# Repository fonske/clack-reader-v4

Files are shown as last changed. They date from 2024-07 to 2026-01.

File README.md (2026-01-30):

# Clack Reader v4
 Esphome component for Clack WS PI (disc valve) Ecosoft LESS and WS1 softener with M5stack TOF sensor saltlevel detection
 
 Relay for control of the chlorinator module from AQMOS
 and Power measurement with ina3221

 Automatic recognision of the softener steps and measure the liters and m3 softened water by reading the clack flowmeter

## 4 Versions / Branches
main: Clack WS PI valve (DiscValve) (ECOSOFT LESS-10 / 15 / 20 from AQMOS)

ws1: Clack WS1 valve (CM(x) from AQMOS)

ws1_usa: Clack WS1 valve with Gallons and Inches / US version

ws1_no_tof: Clack WS1 valve without the TOF sensor code (in case of TOF failure/damaged by water)

Remark: Make sure to copy water_flow.h and tof_vl53l1x.h to your esphome directory before compiling the clack.yaml
There have been some bigger updates to the latest code: added L/min and alarm, also lovelace home assistant menu has been updated.

Remark2: 6 august 2024: Added history regeneration and test button motor pulse to step through regeneration (with time delays stil working between steps)
[example EN](/readme/last_changes_august_2024.jpg)
[example NL](/readme/laaste_wijzigingen_august_2024.jpg)

Remark3: 17 august 2024: Added more options to show the regeneration cycle. Pre fill (dry salt tank) and Post fill (wet salt tank)
Both with or without the 2nd backwash programmed  (between brine and rinse)

      # Pre fill no 2nd Backwash  : FILL/SERVICE/BACKWASH/BRINE/RINSE
      # Pre fill 2nd Backwash     : FILL/SERVICE/BACKWASH/BRINE/BACKWASH2/RINSE
      # Post fill no 2nd Backwash : BACKWASH/BRINE/RINSE/FILL
      # sPost fill 2nd Backwash   : BACKWASH/BRINE/BACKWASH2/RINSE/FILL   

When delivered the Clack reader has already the correct code on the Atom S3 esp.
If needed, there can be downloaded new firmware to the Atom.

***
It is important to connect the TOF sensor to the 4p grove connector near the Atom S3. This needs to be done, before powering the PCB, otherwise the Atom will be in a reboot loop, and no wifi hotspot will be available to connect to.

 ## Dutch:
[README](/readme/clack_uitleg_nl.md)

## English:
[README](/readme/clack_explanation_en.md)

Help: Please open a issue on this git project.

Example

"Buy Me A Coffee" (https://www.buymeacoffee.com/ebbenberg)

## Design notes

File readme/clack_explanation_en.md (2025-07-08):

# Clack Reader V4 with Atom S3 lite and TOF sensor

## Hardware
The kit includes:
- [Atom S3 lite](https://www.tinytronics.nl/shop/nl/development-boards/microcontroller-boards/met-wi-fi/m5stack-atom-s3-lite-esp32-s3-development-board) from M5stack
- [TOF1 sensor](https://www.tinytronics.nl/shop/nl/platformen-en-systemen/m5stack/unit/m5stack-tof-unit)  (vl53l0x) or [TOF2 sensor](https://shop.m5stack.com/products/time-of-flight-distance-unit-vl53l1x) (vl53l1x) from M5stack
  - TOF1 can measure with a Grove cable up to 5 meters (2x 2m + 1x 1m with connector blocks)
  - TOF2 can measure with a Grove cable up to 3 meters (1x 2m + 1x 1m with connector blocks)
- PCB with connectors ([visual overview](../readme/Clack_reader_v4_connections_on_clack_ws1_EN.pdf) of connections)
  - Power in/out - Passthrough connections to monitor power usage and regeneration steps (4-wire connector)
  - Flowmeter in/out - Passthrough connections to monitor water usage (3-wire connector, on back of PCB)
  - DP-SW - Allows for a delayed or immediate regen, or can prevent a regen. Functionality depends on the settings in the softener control itself (refer to the manual)
- [3D printed](../readme/clack_tof-holder.stl)  TOF sensor housing which can be attached to the salt reservoir lid with two stainless steel M4 bolts and nuts

> [!WARNING]
> It is important to connect the TOF sensor to the 4p Grove connector <ins>near</ins>, not on, the Atom S3. This needs to be done before powering the PCB, otherwise the Atom will enter a reboot loop and the Wi-Fi hotspot will not be available to connect to.

## Hardware Images
| Image | Description |
| --- | --- |
| [pcb_front.jpg](../readme/pcb_front.jpg) | Front of Clack Reader |
| [pcb_back.jpg](../readme/pcb_back.jpg) | Back of Clack Reader |
| [mount_position_image1.jpg](../readme/mount_position_image1.jpg) | Best location for mounting Clack Reader inside the Clack WS1 housing |
| [mount_position_image2.jpg](../readme/mount_position_image2.jpg) | Best location for mounting Clack Reader inside the Clack WS1 housing |

## Firmware
The Clack Reader PCB is programmed in ESPHome and arrives preflashed. You can choose to use the supplied version or reflash from this Git repo.

If using the preflashed version, power on the Clack Reader (with the TOF sensor attached), connect to the `Clack` hotspot using the password `configesp`, and enter your network's Wi-Fi details.

# Home Assistant

## Lovelace Dashboard
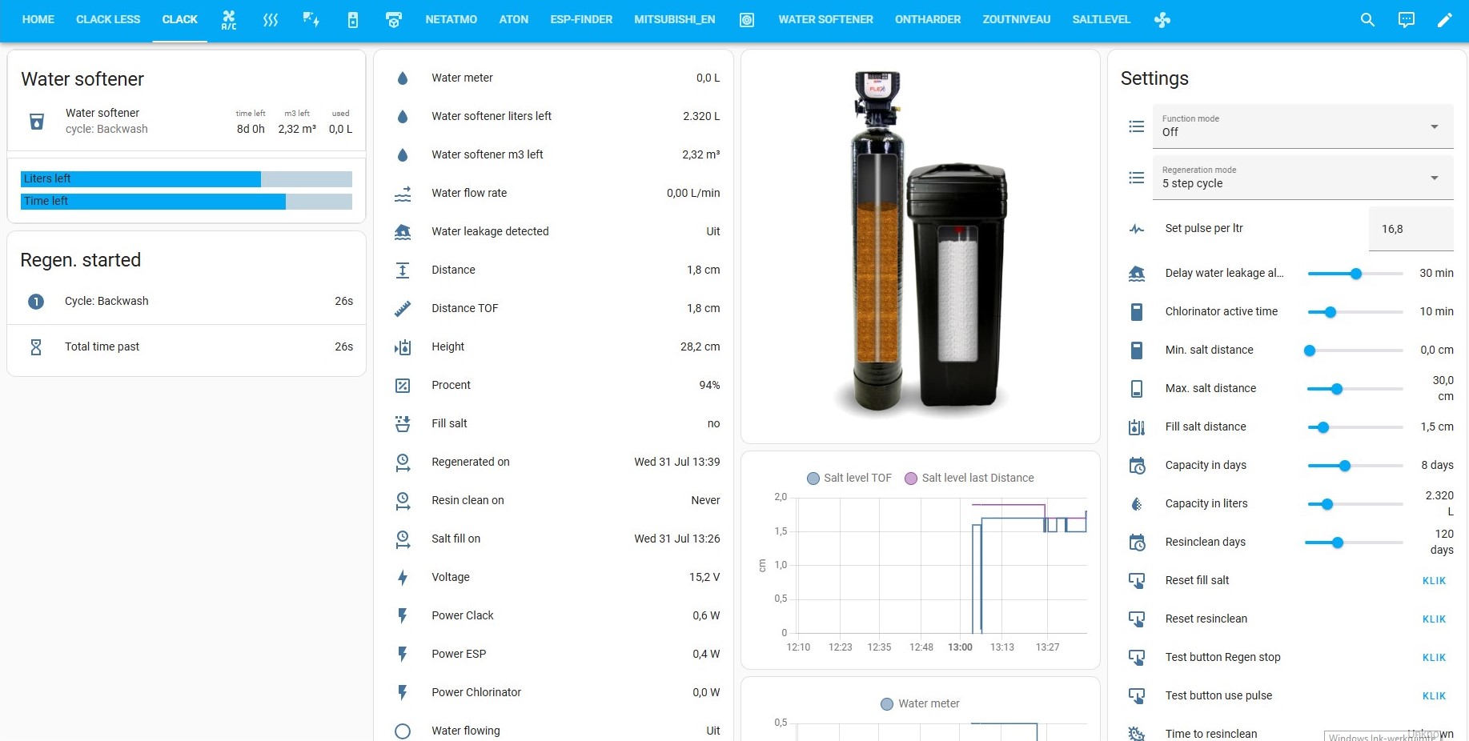
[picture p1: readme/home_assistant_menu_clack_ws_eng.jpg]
Example


To add the dashboard shown above to Home Assistant:
1. Create a `/www/images` folder in your `homeassistant` directory
1. Copy the images from [/www/images](../www/images) into the new folder. These images support the salt level simulation view.
1. Navigate to your Home Assistant dashboard
1. At the top-right, click the pencil (edit dashboard)
1. Click the three dots and select 'Raw configuration editor'
1. Add the text from the appropriate dashboard YAML file from the [homeassistant](../homeassistant) folder of this repo (e.g., [lovelace_menu_Post_fill_with_2nd_backwash_dn_brine_EN.yaml](../homeassistant/lovelace_menu_Post_fill_with_2nd_backwash_dn_brine_EN.yaml)) and save
1. You will now have a new Clack view in Home Assistant

> [!IMPORTANT]
> To properly view the status bar, use [HACS](https://hacs.xyz) to install the following frontend applications (subject to change):
> - bar-card https://github.com/spacerokk/bar-card
> - multiple-entity-row
> - stack-in-card

## Automations
It is possible to receive notifications on a mobile phone running the Home Assistant app. For example, when a possible water leak is detected or when salt runs low. Sample automations are provided in [clack_en.yaml](../homeassistant/clack_en.yaml). The options below can be used to add these automations to Home Assistant.

> [!IMPORTANT]
> Modify the `action` values to use your own mobile device (e.g., replace `- action: notify.mobile_app_iphone_van_a_c_a`)

### Option 1 - Use Home Assistant [Packages](https://www.home-assistant.io/docs/configuration/packages/) functionality
1. Create a folder under `/config`, preferably named `packages`, and copy [clack_en.yaml](../homeassistant/clack_en.yaml) to the directory
1. Adjust your `configuration.yaml` to add:

>```yml
> homeassistant:
>   packages: !include_dir_named packages
> ```

3. Restart Home Assistant

> [!WARNING]
> While automations added using the [Packages](https://www.home-assistant.io/docs/configuration/packages/) pattern are visible in Home Assistant on the `Settings/Automations` screen, they are not modifiable via the Home Assistant UI. To modify them, edit the package YAML file and restart Home Assistant.

### Option 2 - Merge clack_en.yaml with automations.yaml
Merge the `automations:` section of [clack_en.yaml](../homeassistant/clack_en.yaml) with automations.yaml (pay attention to indentations).

## Configuration

Use the sliders on the dashboard to configure the system.

> [!TIP]
> A diagram explaining min/max salt distance can be found [here.](../readme/min_max_EN.jpg)

| Setting | Description | Example |
| --- | --- | ---- |
| Delay water leakage alarm | Minutes of constant water flow that will trigger `binary_sensor.clack_leakage_detected` to turn `true`, allowing automations (alerts) to trigger | 30 min |
| Min. salt distance | Distance between the TOF sensor and the salt <ins>when the salt container is full</ins> | 10 cm. |
| Max. salt distance | Distance between the TOF sensor and the salt <ins>when the salt is at its lowest level</ins> (empty)| 35 cm. |
| Fill salt distance | Centimeters of salt remaining in the tank, below which `sensor.clack_fill_salt` turns `true` and automations (alerts) may trigger | 5 cm. |
| Capacity in days | Number of days the Clack controller is set to regen at if the liters of capacity has not yet been exceeded | 14 days |
| Capacity in liters | Liters of capacity that the Clack controller displays immediately after a regen | 3500 ltr. |
| Pulses per ltr | Pulse meter is used to measure water flow. It measures pulses per minute. To convert pulses into liters of water this setting is used. The bigger this value the slower water flow will be. | 16.3 pulses/ltr. |
| Water flow timeout | If no water flow pulse is detected in this amount of time then water flow will be considered 0. The bigger is this value the longer it will take for water flow meter to detect that flow has stopped. But the bigger this value the smaller quantities of flowing water will be detectable by the water flow meter. | 7 s |

## Explanation of Operation

### Salt Measurement Logic
Since many water softeners have water above the salt (small salt reservoir), there is a smart function built into the distance measurement.

The sensor measures the distance downwards to the salt. That measured distance should be expected to only increase as the salt depletes.
Because of this, shorter distances are not recorded as the most recent value, only longer ones. This way, water rising above the salt does not affect the measurement.

There are two readings: Distance and TOF Distance.
Distance is the measurement with the smart function. TOF Distance is continuously measured every 10 seconds but has no effect on the 'Clack salt level percent' and does not affect Distance unless the it measures greater than Distance.

### Refilling Salt

When refilling your salt container, press the 'Reset fill salt' button on the dashboard. This will equalize the TOF Distance and Distance values, thereby resetting the distance measurement so that the new salt level can be measured and recorded again. Recall that the smart function would otherwise not let Distance increase.

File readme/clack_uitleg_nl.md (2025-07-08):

# Clack Reader V4 met Atom S3 lite en TOF sensor

## Hardware
De kit bevat:
- [Atom S3 lite](https://www.tinytronics.nl/shop/nl/development-boards/microcontroller-boards/met-wi-fi/m5stack-atom-s3-lite-esp32-s3-development-board) van M5stack
- [TOF1 sensor](https://www.tinytronics.nl/shop/nl/platformen-en-systemen/m5stack/unit/m5stack-tof-unit) (vl53l0x) of [TOF2 sensor](https://shop.m5stack.com/products/time-of-flight-distance-unit-vl53l1x) (vl53l1x) van M5stack
  - TOF1 kan met een Grove kabel tot 5 meter meten (2x 2m + 1x 1m met connectorblokje)
  - TOF2 kan met een Grove kabel tot 3 meter meten (1x 2m + 1x 1m met connectorblokje)
- PCB met connectors ([visueel overzicht](../readme/Clack_reader_v4_connections_on_clack_ws1_EN.pdf) van de aansluitingen)
  - Stroom in/uit - Doorgeefverbindingen om het stroomverbruik en regeneratiestappen te monitoren (4-draads connector)
  - Flowmeter in/uit - Doorgeefverbindingen om het waterverbruik te monitoren (3-draads connector, aan de achterkant van de PCB)
  - DP-SW - Hiermee kan een vertraagde of onmiddellijke regeneratie worden gestart of kan regeneratie worden voorkomen. De functionaliteit hangt af van de instellingen in de waterontharder zelf (raadpleeg de handleiding)
- [3D-geprinte](../readme/clack_tof-holder.stl) TOF sensorbehuizing die met twee roestvrijstalen M4 bouten en moeren aan het deksel van het zoutreservoir kan worden bevestigd

> [!WARNING]
> Het is belangrijk om de TOF sensor aan te sluiten op de 4p Grove connector <ins>dichtbij</ins>, niet op, de Atom S3. Dit moet gebeuren voordat de PCB van stroom wordt voorzien, anders zal de Atom in een herstartlus komen en zal de Wi-Fi hotspot niet beschikbaar zijn om verbinding mee te maken.

## Hardware afbeeldingen
| Afbeelding | Beschrijving |
| --- | --- |
| [pcb_front.jpg](../readme/pcb_front.jpg) | Voorkant van Clack Reader |
| [pcb_back.jpg](../readme/pcb_back.jpg) | Achterkant van Clack Reader |
| [mount_position_image1.jpg](../readme/mount_position_image1.jpg) | Beste locatie voor het monteren van Clack Reader in de Clack WS1 behuizing |
| [mount_position_image2.jpg](../readme/mount_position_image2.jpg) | Beste locatie voor het monteren van Clack Reader in de Clack WS1 behuizing |

## Firmware
De Clack Reader PCB is geprogrammeerd in ESPHome en wordt vooraf geflasht geleverd. Je kunt ervoor kiezen om de meegeleverde versie te gebruiken of opnieuw te flashen vanuit deze Git-repo.

Als je de vooraf geflashte versie gebruikt, schakel dan de Clack Reader in (met de TOF sensor aangesloten), maak verbinding met de `Clack` hotspot met het wachtwoord `configesp`, en voer de Wi-Fi gegevens van je netwerk in.

# Home Assistant

## Lovelace Dashboard
Voorbeeld

Om het bovenstaande dashboard toe te voegen aan Home Assistant:
1. Maak een map `/www/images` in je `homeassistant` directory
1. Kopieer de afbeeldingen van [/www/images](../www/images) naar de nieuwe map. Deze afbeeldingen ondersteunen de weergave van de zoutniveau-simulatie.
1. Navigeer naar je Home Assistant dashboard
1. Klik rechtsboven op het potlood (dashboard bewerken)
1. Klik op de drie puntjes en selecteer 'Ruwe configuratie editor'
1. Voeg de tekst toe van het juiste dashboard YAML bestand uit de [homeassistant](../homeassistant) map van deze repo (bijv. [lovelace_menu_Post_fill_with_2nd_backwash_dn_brine_NL.yaml](../homeassistant/lovelace_menu_Post_fill_with_2nd_backwash_dn_brine_NL.yaml)) en sla op
1. Je hebt nu een nieuwe Clack weergave in Home Assistant

> [!IMPORTANT]
> Om de statusbalk correct weer te geven, gebruik [HACS](https://hacs.xyz) om de volgende frontend applicaties te installeren (onder voorbehoud van wijzigingen):
> - bar-card  https://github.com/spacerokk/bar-card
> - multiple-entity-row
> - stack-in-card

## Automatiseringen
Het is mogelijk om meldingen te ontvangen op een mobiele telefoon die de Home Assistant app gebruikt. Bijvoorbeeld wanneer een mogelijk waterlek wordt gedetecteerd of wanneer het zout opraakt. Voorbeeldautomatiseringen zijn beschikbaar in [clack_nl.yaml](../homeassistant/clack_nl.yaml). De onderstaande opties kunnen worden gebruikt om deze automatiseringen toe te voegen aan Home Assistant.

> [!IMPORTANT]
> Pas de `action` waarden aan om je eigen mobiele apparaat te gebruiken (bijv. vervang `- action: notify.mobile_app_iphone_van_a_c_a`)

### Optie 1 - Gebruik de Home Assistant [Packages](https://www.home-assistant.io/docs/configuration/packages/) functionaliteit
1. Maak een map onder `/config`, bij voorkeur genaamd `packages`, en kopieer [clack_nl.yaml](../homeassistant/clack_nl.yaml) naar de directory
1. Pas je `configuration.yaml` aan om toe te voegen:

>```yml
> homeassistant:
>   packages: !include_dir_named packages
> ```

3. Herstart Home Assistant

> [!WARNING]
> Hoewel automatiseringen die zijn toegevoegd met behulp van het [Packages](https://www.home-assistant.io/docs/configuration/packages/) patroon zichtbaar zijn in Home Assistant op het `Settings/Automations` scherm, kunnen ze niet worden gewijzigd via de Home Assistant UI. Om ze te wijzigen, bewerk je het package YAML bestand en herstart je Home Assistant.

### Optie 2 - Voeg clack_en.yaml samen met automations.yaml
Voeg de `automations:` sectie van [clack_nl.yaml](../homeassistant/clack_nl.yaml) samen met automations.yaml (let op de inspringingen).

## Configuratie

Gebruik de schuifregelaars op het dashboard om het systeem te configureren.

> [!TIP]
> Een diagram dat de min/max zoutafstand uitlegt, is hier te vinden. [hier.](../readme/min_max_NL.jpg)

| Instelling | Beschrijving | Voorbeeld |
| --- | --- | ---- |
| Vertraging waterlek alarm | Minuten van constante waterstroom die `binary_sensor.clack_leakage_detected` zal activeren om `true` te worden, waardoor automatiseringen (meldingen) kunnen worden geactiveerd | 30 min |
| Min. zoutafstand | Afstand tussen de TOF sensor en het zout <ins>wanneer de zoutcontainer vol is</ins> | 10 cm |
| Max. zoutafstand | Afstand tussen de TOF sensor en het zout <ins>wanneer het zout op het laagste niveau is</ins> (leeg)| 35 cm |
| Vul zoutafstand | Inches zout die nog in de tank zit, waaronder `sensor.clack_fill_salt` `true` wordt en automatiseringen (meldingen) kunnen worden geactiveerd | 4 cm |
| Capaciteit in dagen | Aantal dagen dat de Clack controller is ingesteld om te regenereren als het aantal gallons capaciteit nog niet is overschreden | 14 dagen |
| Capaciteit in liters | Liters capaciteit die de Clack controller weergeeft direct na een regeneratie | 3500 ltr |

## Uitleg werking

### Zoutmeetlogica
Aangezien veel waterontharders water boven het zout hebben (klein zoutreservoir), is er een slimme functie ingebouwd in de afstandsmeting.

De sensor meet de afstand naar beneden tot het zout. Die gemeten afstand zou alleen moeten toenemen naarmate het zout afneemt.
Hierdoor worden kortere afstanden niet geregistreerd als de meest recente waarde, alleen langere. Op deze manier beïnvloedt het stijgende water boven het zout de meting niet.

Er zijn twee metingen: Afstand en TOF Afstand.
Afstand is de meting met de slimme functie. TOF Afstand wordt continu elke 10 seconden gemeten maar heeft geen invloed op het 'Clack zoutniveau percentage' en beïnvloedt de Afstand niet tenzij het groter meet dan de Afstand.

### Zout bijvullen

Bij het bijvullen van je zoutcontainer druk je op de 'Reset fill salt' knop op het dashboard. Dit zal de TOF Afstand en Afstand gelijkmaken, waardoor de afstandsmeting opnieuw wordt ingesteld zodat het nieuwe zoutniveau opnieuw kan worden gemeten en geregistreerd. Onthoud dat de slimme functie anders de Afstand niet zou laten toenemen.

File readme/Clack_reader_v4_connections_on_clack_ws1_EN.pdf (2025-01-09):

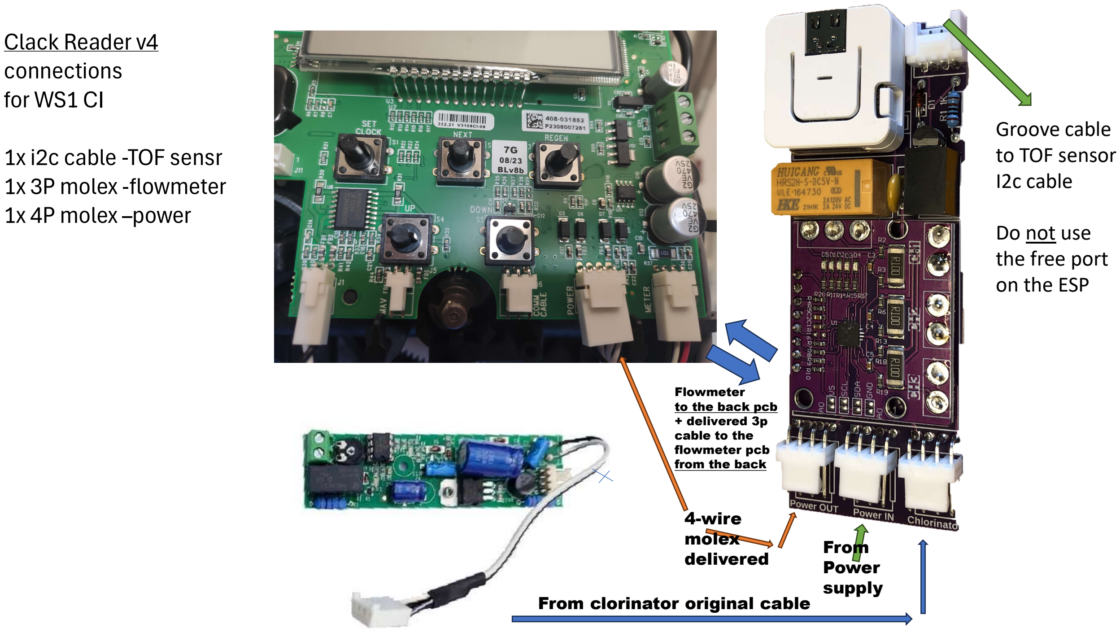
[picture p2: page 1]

4-wire
molex
delivered | From
| Power
| supply
From clorinator original cable

Flowmeter
to the back pcb
+ delivered 3p
cable to the
flowmeter pcb
from the back

Clack Reader v4
connections
for WS1 CI

1x i2c cable -TOF sensr
1x 3P molex -flowmeter
1x 4P molex –power

Groove cable
to TOF sensor
I2c cable

Do not use
the free port
on the ESP

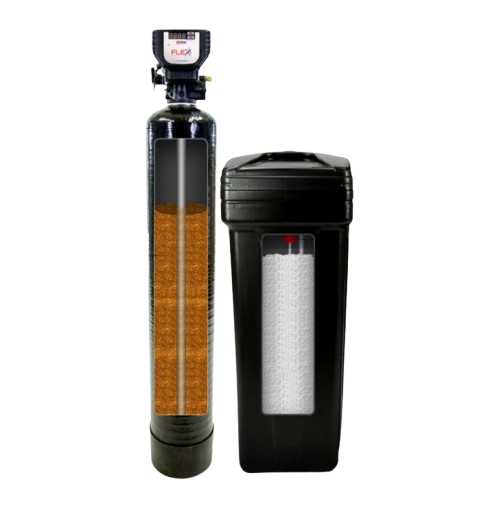
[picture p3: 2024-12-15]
www/images/softener100.png

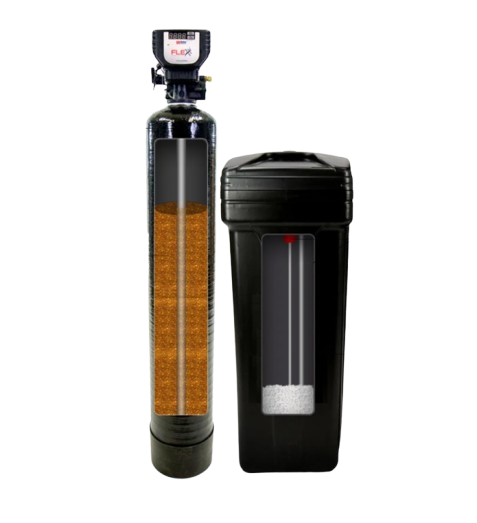
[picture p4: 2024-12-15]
www/images/softener10.png

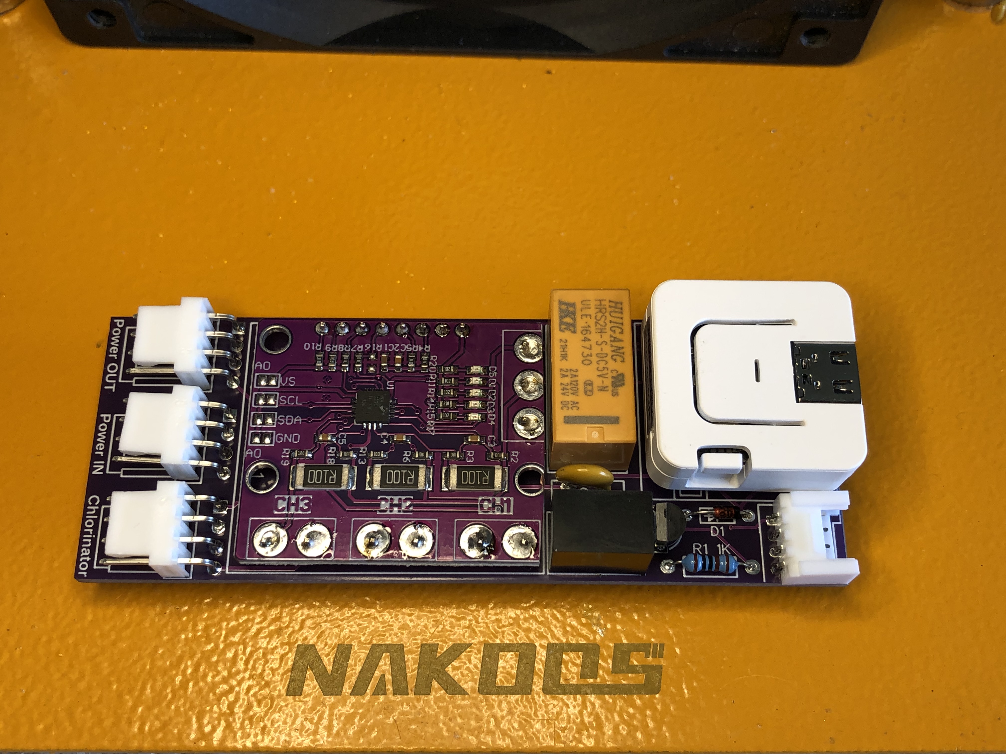
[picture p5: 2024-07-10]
readme/pcb_front.jpg

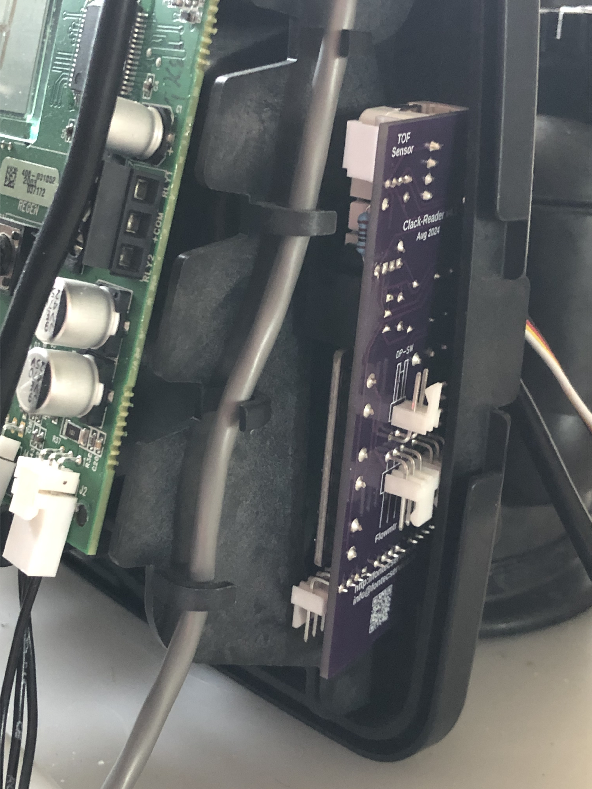
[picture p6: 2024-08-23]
readme/mount_position_image1.jpg

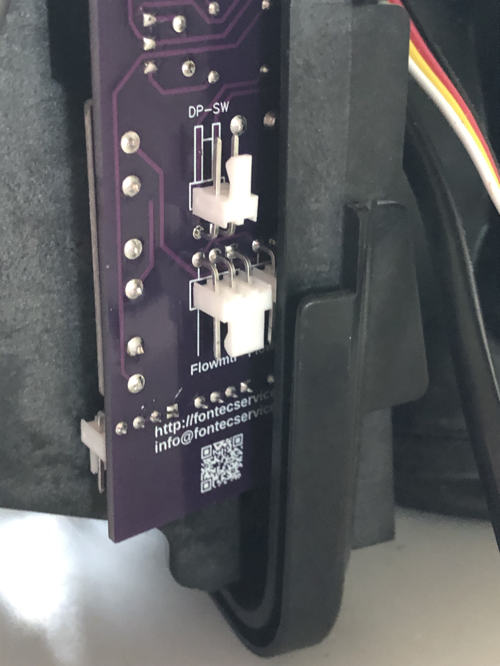
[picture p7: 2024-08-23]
readme/mount_position_image2.jpg

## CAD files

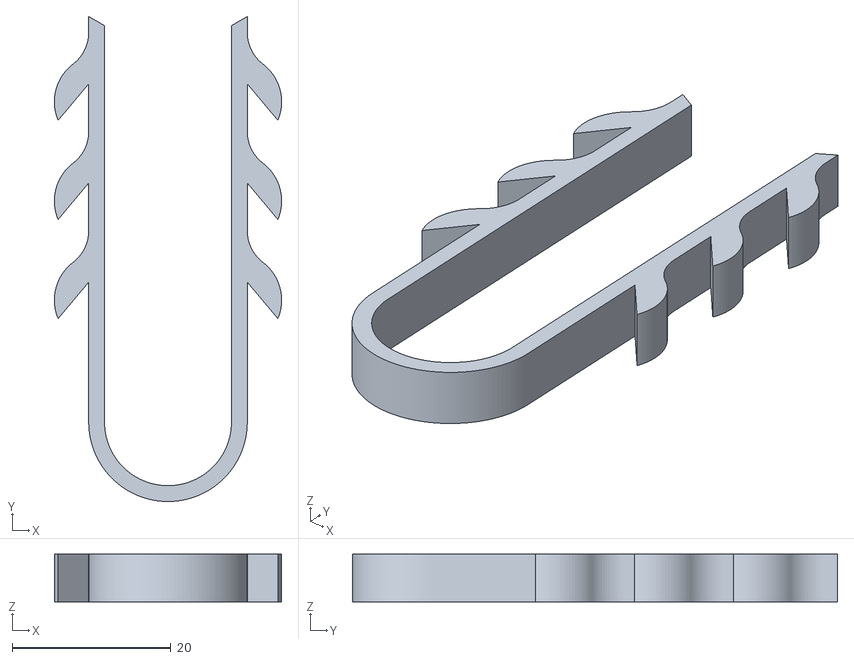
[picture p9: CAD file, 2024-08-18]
readme/Airgap_3d_thomox/Piepschuim_plug.stl
28.7 x 61.2 x 6.00

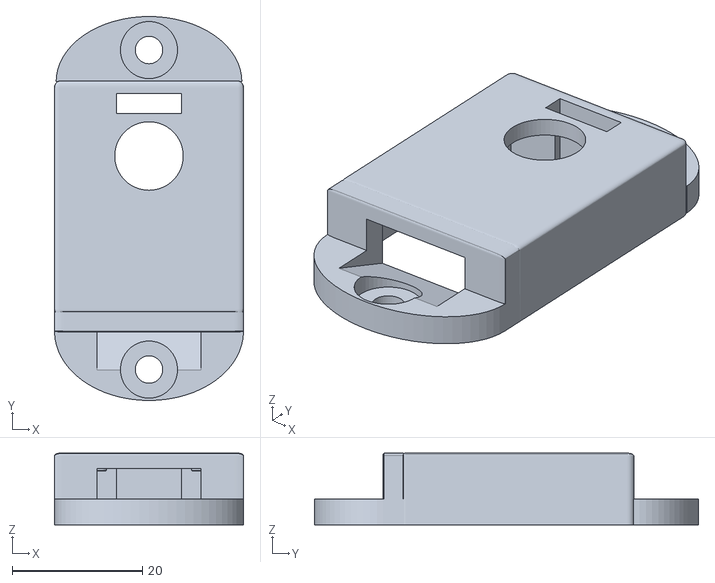
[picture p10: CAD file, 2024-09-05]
readme/clack_tof-holder.stl
29.0 x 58.9 x 11.0

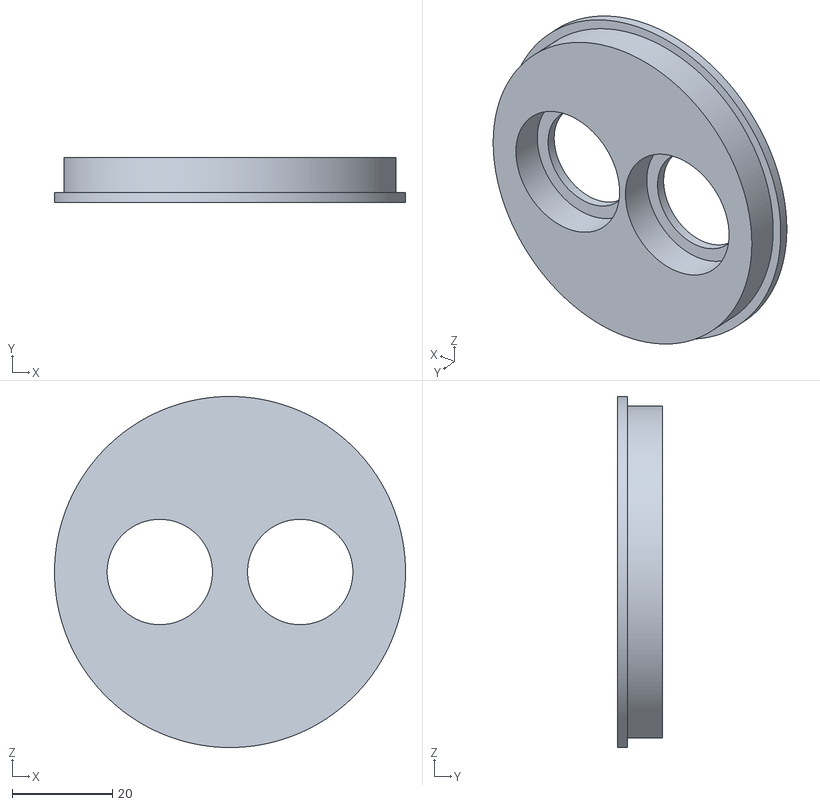
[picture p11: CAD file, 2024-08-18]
readme/Airgap_3d_thomox/Deksel airgap V2.stl
70.0 x 9.00 x 70.0

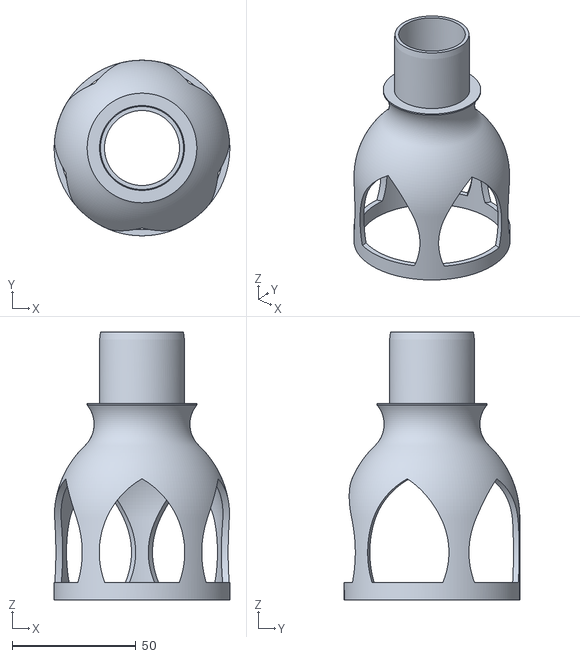
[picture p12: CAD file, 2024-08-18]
readme/Airgap_3d_thomox/Airgap_v4.stl
71.0 x 71.0 x 108.3

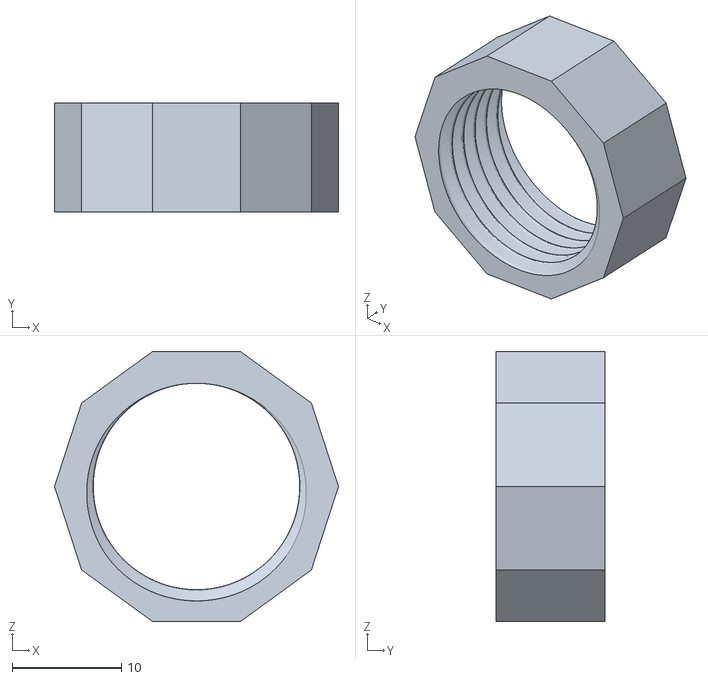
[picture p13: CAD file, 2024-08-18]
readme/Airgap_3d_thomox/half_inch_nut.stl
26.0 x 10.0 x 24.7

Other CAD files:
readme/Airgap_3d_thomox/Airgap_v4.f3d
readme/Airgap_3d_thomox/deksel airgap v2.f3d

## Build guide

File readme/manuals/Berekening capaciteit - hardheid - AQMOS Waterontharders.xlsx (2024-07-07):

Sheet: Dashboard
Selecteer je model: |  |  | Hardheid (°dH) | LESS-10 | -10%
LESS-10 |  |  |  | In liter (L) | In liter (L) | Model | C-waarde
 |  |  |  |  |  | LESS-10 | C 25
 |  |  | 7.5 | 3700 | 3300 | LESS-15 | C 37
 |  |  | 10 | 2800 | 2500 | LESS-20 | C 63
 |  |  | 11 | 2500 | 2200
Voer je waterhardheid in (°dH): |  |  | 12 | 2300 | 2100 | Voer bovenstaande waardes in bij C=. (Navigeer naar menu: ↳ + ⭣) Let op dat je de waterontharder hebt ingesteld op dH in plaats van PPM! (Zelfde menu, waarde "U" instellen op dH). Vergeet niet je hardheid in te stellen! (Navigeer naar menu: ↳ + ⭡)
10 |  |  | 13 | 2100 | 1900
 |  |  | 14 | 2000 | 1800
 |  |  | 15 | 1800 | 1600
De capaciteit van je waterontharder is: | 2800 |  | 16 | 1700 | 1500
Wij raden de volgende waarde aan om in te stellen (10% marge): | 2500 | ⭠Voer deze waarde NIET in bij C=. Deze waarde is puur indicatief. Zie de C waarde naast de tabel. | 17 | 1600 | 1400
Er zitten meerdere "storende ionen" in het water die vastgehouden worden door het hars. Denk bijvoorbeeld aan ijzer, mangaan, natrium. Daarom raden wij een kleine marge aan. (Dit is ook de reden waarom harsreiniger gebruiken belangrijk is.) |  |  | 18 | 1500 | 1400
 |  |  | 19 | 1400 | 1300
 |  |  | 20 | 1400 | 1200
 |  |  | 21 | 1300 | 1200
 |  |  | 22 | 1200 | 1100
 |  |  | 23 | 1200 | 1000
 |  |  | 24 | 1100 | 1000
 |  |  | 25 | 1100 | 1000
 |  |  | 26 | 1000 | 900
 |  |  | 27 | 1000 | 900
 |  |  | 28 | 1000 | 900
 |  |  | 29 | 900 | 800
 |  |  | 30 | 900 | 800
 |  |  | 31 | 900 | 800
 |  |  | 32 | 800 | 700
 |  |  | 33 | 800 | 700
 |  |  | 34 | 800 | 700
 |  |  | 35 | 800 | 700

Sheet: Data
Model? | Column1 | X Hars | Operating capacity
Anders |  | 10 | 0.499
LESS-10
LESS-15
LESS-20
R2D2-32
R2D2-48
R2D2-72

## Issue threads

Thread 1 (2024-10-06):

Pulse conter needed for flow meter?

OwlBawl, 2024-10-06:
Errors in log related to water flow meter in HA

```
2024-10-06 11:48:42.576 WARNING (MainThread) [homeassistant.components.sensor] Entity sensor.clack_water_flow_rate (<class 'homeassistant.components.esphome.sensor.EsphomeSensor'>) is using state class 'measurement' which is impossible considering device class ('water') it is using; expected None or one of 'total', 'total_increasing'; Please update your configuration if your entity is manually configured, otherwise create a bug report at https://github.com/home-assistant/core/issues?q=is%3Aopen+is%3Aissue+label%3A%22integration%3A+esphome%22
2024-10-06 11:48:42.577 WARNING (MainThread) [homeassistant.components.sensor] Entity sensor.clack_water_flow_rate (<class 'homeassistant.components.esphome.sensor.EsphomeSensor'>) is using native unit of measurement 'L/min' which is not a valid unit for the device class ('water') it is using; expected one of ['gal', 'm³', 'CCF', 'ft³', 'L']; Please update your configuration if your entity is manually configured, otherwise create a bug report at https://github.com/home-assistant/core/issues?q=is%3Aopen+is%3Aissue+label%3A%22integration%3A+esphome%22
```

OwlBawl, 2024-10-06:
Found this one, changed in my code, would test:
device_class: volume_flow_rate
state_class: measurement

fonske, 2024-10-06:
Thank you.

I have made the changes.

Closed 2024-10-06.

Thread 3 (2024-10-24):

Need your help... after ESPhome 2024.10.2 Update it gone "offline" and can't get it work.

OwlBawl, 2024-10-24:
Can see it as WiFi client in router but ESPhome dont establish connection, web portal not working also.
First symptom after update was False "Regen start / Regen end" with "binary_sensor.clack_block_regen" active
Reseted it with "button.clack_test_button_regen_stop" to restore work, then rebooted the esp32 and thats all. Tried upload recompiled firmware via OTA but also no luck...

thedudefxp, 2024-10-24:
Does he get ip ?
i had some thing last time its was lost the information in secrets.yalm. It show on router wifi but no ip lease

fonske, 2024-10-24:
I have just updated with the newest version of esphome but everything works.

Do you use the correct github branch for your model?
And check  secrets.yaml indeed if correct setting for your wifi

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

OwlBawl, 2024-10-24:
As i see arduiono framework also updated recently... maybe that's the problem also... don't know

OwlBawl, 2024-10-24:
> Does he get ip ? i had some thing last time its was lost the information in secrets.yalm. It show on router wifi but no ip lease

yes, it receives IP from router and router even ping it
tries ping from HA terminal successfully also.

OwlBawl, 2024-10-24:
recompiled using exteranal git component - also not API connection.... while pinging

fonske, 2024-10-24:
Is your TOF sensor connected?  Otherwise you could have reboots
best to have it on Clack power and not usb, for clack reader V4
warning: do not connect or disconnect any power cables when power is on.

OwlBawl, 2024-10-24:
Would check, but didn't touch it
It connectecd with cable to Clack reader, and clack reader powered by Clack 15V? (as i remember voltage)

fonske, 2024-10-24:
Yes i think its correct
https://github.com/fonske/clack-reader-v4/blob/ws1/readme/Clack_reader_v4.1_connections_on_clack_ws1.pdf

OwlBawl, 2024-10-24:
TOF cords are connected...
It sent false Regen start at night (the regen is scheduled on 14:00 at day, and resourse wasn't used yet for regen)
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
co

In HA from same 3:20 sensors resetet to 0 as it was regen, and from 5:10 all entities became unavailable...
I succesfully rebooted it once in the morning 8:15 and it established API connection, and after 9:10 it gone offline till now...

Made few OTA updates already, rebotted my Unifi router and AP's... reboted HA and so on.

OwlBawl, 2024-10-24:
> Yes i think its correct https://github.com/fonske/clack-reader-v4/blob/ws1/readme/Clack_reader_v4.1_connections_on_clack_ws1.pdf

yes, it's connected from the beginning as it sholt ad worked almost 2 mnths so
(from ~9.09.24)
But yes, anything could happen ofcourse

OwlBawl, 2024-10-24:
But as i see in router history - it don't powercycle. it connects to wifi and that's all
I can use captivate_portal for OTA blocking it from WiFi connection but web_portal not responsive

fonske, 2024-10-24:
Maybe you can try a basic configuration first
https://github.com/fonske/clack-reader-v4/blob/ws1/esphome/clack_test.yaml

To see if a tof sensor connection is a problem or not  (reboots when there is a problem with it)

OwlBawl, 2024-10-24:
That's seems good.
I can open web portal, can see it in ESPhome now

Should I wait for reboots some time?

OwlBawl, 2024-10-24:
`INFO ESPHome 2024.10.2
INFO Reading configuration /config/esphome/clack-reader-v4.yaml...
WARNING GPIO35 is used by the PSRAM interface on ESP32-S3R8 / ESP32-S3R8V and should be avoided on these models
INFO Starting log output from 10.10.20.213 using esphome API
INFO Successfully connected to clack-test @ 10.10.20.213 in 0.066s
INFO Successful handshake with clack-test @ 10.10.20.213 in 0.019s
[21:22:29][I][app:100]: ESPHome version 2024.10.2 compiled on Oct 24 2024, 21:17:59
[21:22:29][C][wifi:600]: WiFi:
[21:22:29][C][wifi:428]:   Local MAC: 34:B7:DA:57:3B:40
[21:22:29][C][wifi:433]:   SSID: 'daad.iot'[redacted]
[21:22:29][C][wifi:436]:   IP Address: 10.10.20.213
[21:22:29][C][wifi:440]:   BSSID: 7A:45:58:17:ED:C1[redacted]
[21:22:29][C][wifi:441]:   Hostname: 'clack-test'
[21:22:29][C][wifi:443]:   Signal strength: -60 dB ▂▄▆█
[21:22:29][C][wifi:447]:   Channel: 6
[21:22:29][C][wifi:448]:   Subnet: 255.255.255.0
[21:22:29][C][wifi:449]:   Gateway: 10.10.20.1
[21:22:29][C][wifi:450]:   DNS1: 10.10.20.1
[21:22:29][C][wifi:451]:   DNS2: 0.0.0.0
[21:22:29][C][logger:185]: Logger:
[21:22:29][C][logger:186]:   Level: DEBUG
[21:22:29][C][logger:188]:   Log Baud Rate: 0
[21:22:29][C][logger:189]:   Hardware UART: USB_CDC
[21:22:29][C][logger:193]:   Level for 'esp32.preferences': DEBUG
[21:22:29][C][logger:193]:   Level for 'sensor': DEBUG
[21:22:29][C][logger:193]:   Level for 'text_sensor': DEBUG
[21:22:29][C][logger:193]:   Level for 'switch': DEBUG
[21:22:29][C][logger:193]:   Level for 'button': DEBUG
[21:22:29][C][logger:193]:   Level for 'number': DEBUG
[21:22:29][C][logger:193]:   Level for 'component': ERROR
[21:22:29][C][uptime.sensor:033]: Uptime Sensor 'clack_uptime'
[21:22:29][C][uptime.sensor:033]:   Device Class: 'duration'
[21:22:29][C][uptime.sensor:033]:   State Class: 'total_increasing'
[21:22:29][C][uptime.sensor:033]:   Unit of Measurement: 'days'
[21:22:29][C][uptime.sensor:033]:   Accuracy Decimals: 1
[21:22:29][C][uptime.sensor:033]:   Icon: 'mdi:timer-outline'
[21:22:29][C][uptime.sensor:034]:   Type: Seconds
[21:22:29][C][esp32_rmt_led_strip:187]: ESP32 RMT LED Strip:
[21:22:29][C][esp32_rmt_led_strip:188]:   Pin: 35
[21:22:29][C][esp32_rmt_led_strip:189]:   Channel: 1
[21:22:29][C][esp32_rmt_led_strip:214]:   RGB Order: GRB
[21:22:29][C][esp32_rmt_led_strip:215]:   Max refresh rate: 0
[21:22:29][C][esp32_rmt_led_strip:216]:   Number of LEDs: 4
[21:22:29][C][gpio.binary_sensor:015]: GPIO Binary Sensor 'esp_button'
[21:22:29][C][gpio.binary_sensor:016]:   Pin: GPIO41
[21:22:29][C][light:103]: Light 'Led'
[21:22:29][C][light:105]:   Default Transition Length: 1.0s
[21:22:29][C][light:106]:   Gamma Correct: 2.80
[21:22:29][C][version.text_sensor:021]: Version Text Sensor 'clack_version'
[21:22:29][C][version.text_sensor:021]:   Icon: 'mdi:new-box'
[21:22:29][C][restart.button:017]: Restart Button 'ESP restart'
[21:22:29][C][restart.button:017]:   Icon: 'mdi:restart'
[21:22:29][C][captive_portal:089]: Captive Portal:
[21:22:29][C][web_server:153]: Web Server:
[21:22:29][C][web_server:154]:   Address: clack-test.local:80
[21:22:29][C][sntp:048]: SNTP Time:
[21:22:29][C][sntp:049]:   Server 1: '0.pool.ntp.org'
[21:22:29][C][sntp:050]:   Server 2: '1.pool.ntp.org'
[21:22:29][C][sntp:051]:   Server 3: '2.pool.ntp.org'
[21:22:29][C][sntp:052]:   Timezone: 'EET-2EEST,M3.5.0/3,M10.5.0/4'
[21:22:29][C][mdns:116]: mDNS:
[21:22:29][C][mdns:117]:   Hostname: clack-test
[21:22:29][C][esphome.ota:073]: Over-The-Air updates:
[21:22:29][C][esphome.ota:074]:   Address: clack-test.local:3232
[21:22:29][C][esphome.ota:075]:   Version: 2
[21:22:29][C][safe_mode:018]: Safe Mode:
[21:22:29][C][safe_mode:020]:   Boot considered successful after 60 seconds
[21:22:29][C][safe_mode:021]:   Invoke after 10 boot attempts
[21:22:29][C][safe_mode:023]:   Remain in safe mode for 300 seconds
[21:22:29][C][api:140]: API Server:
[21:22:29][C][api:141]:   Address: clack-test.local:6053
[21:22:29][C][api:145]:   Using noise encryption: NO
[21:22:29][C][wifi_signal.sensor:010]: WiFi Signal 'clack_wifi_signal_db'
[21:22:29][C][wifi_signal.sensor:010]:   Device Class: 'signal_strength'
[21:22:29][C][wifi_signal.sensor:010]:   State Class: 'measurement'
[21:22:29][C][wifi_signal.sensor:010]:   Unit of Measurement: 'dBm'
[21:22:29][C][wifi_signal.sensor:010]:   Accuracy Decimals: 0
[21:22:29][C][wifi_info:010]: WifiInfo IPAddress 'Clack IP'
[21:22:29][C][wifi_info:010]:   Icon: 'mdi:ip-network'
[21:22:34][D][sensor:094]: 'clack_wifi_signal_db': Sending state -59.00000 dBm with 0 decimals of accuracy
[21:23:34][D][sensor:094]: 'clack_wifi_signal_db': Sending state -59.00000 dBm with 0 decimals of accuracy
[21:24:34][D][sensor:094]: 'clack_wifi_signal_db': Sending state -58.00000 dBm with 0 decimals of accuracy
`

OwlBawl, 2024-10-24:
I begin supposing it's kinda weird IP network problem, the only thing changed - dynamic IP adress and so new IP

fonske, 2024-10-24:
The reboots happen when there is a problem with the tof sensor or the connection to it.
And you wont be able to see the ESP or the entities in home assistant. They become unavailable.

You could connect a tof sensor directly to the grove port on the atom and see for some log messages about i2c
```
i2c:
  - id: bus_a
    sda: GPIO2
    scl: GPIO1
    frequency: 800kHz
    timeout: 50ms
```

OwlBawl, 2024-10-24:
> I begin supposing it's kinda weird IP network problem, the only thing changed - dynamic IP adress and so new IP while other 11 esp's are working fine damn it Will try to disable IP static for test in main config

nope, just as I swithced back to my main config without static IP - API / Log  unavailable again
Would write your test config till tomorrow and have a rest for today.

OwlBawl, 2024-10-25:
ok, so on the test firmware it worked last 12 hours with uptime
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
Should i then switch tof to grove and see logs?

OwlBawl, 2024-10-25:
hmm

added this to test.yaml

i2c:
  - id: bus_a
    sda: GPIO2
    scl: GPIO1
    frequency: 800kHz
    timeout: 50ms

connected tof via cable extender I use - WiFi up, but no API
connected tof via short cable without extender to m5stack - Wifi up, API ok, log NOT ok as I understand:

```
[10:10:54][C][i2c.arduino:071]: I2C Bus:
[10:10:54][C][i2c.arduino:072]:   SDA Pin: GPIO2
[10:10:54][C][i2c.arduino:073]:   SCL Pin: GPIO1
[10:10:54][C][i2c.arduino:074]:   Frequency: 800000 Hz
[10:10:54][C][i2c.arduino:077]:   Timeout: 50 ms
[10:10:54][C][i2c.arduino:086]:   Recovery: bus successfully recovered
[10:10:54][I][i2c.arduino:096]: Results from i2c bus scan:
[10:10:54][I][i2c.arduino:098]: Found no i2c devices!
```
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

And so i took of TOF and disassembled it...
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
It definitely doesn't like place it should leave in ))

OwlBawl, 2024-10-25:
I'll try to clear it and test then, but, anyway, would appreciate if you can help me to comment out all ToF related stuff to just use / test reader without ToF (anyway with my small tank it's not so necessary for now, but need to monitor regen / block regen and so on)

fonske, 2024-10-25:
I will try this weekend to change the code for you.
Will take some time to check and adjust

fonske, 2024-10-25:
Hi @OwlBawl

Can you try this version?
branch ws1_no_tof
https://github.com/fonske/clack-reader-v4/blob/ws1_no_tof/esphome/clack.yaml

The TOF sensor is taken out of the code
I have tested it without the TOF sensor connected and the ESP works and entity's are visable.

OwlBawl, 2024-10-25:
Thank you so much!
It works
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

All this problems really were because of ToF death so.
So glad to see it online again after two days of findings )

OwlBawl, 2024-10-25:
As i understand this ones are also unusable without ToF?
sensor.clack_fill_salt
button.clack_reset_fill_salt
'#' them in lovelace.
Maybe I would order ToF later or leave it as is, counting my conditions of use. Thank you for your help.

fonske, 2024-10-25:
I can 3d print also a sensor housing that fits ON the cover, maybe thats a bit more protected, when filling new salt, as the cover is taken off already.
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

Just let me know if that would be a better solution for you.

OwlBawl, 2024-10-25:
Thank you, you can just share the 3D model and I'll print it somewhere locally not to bother you and eliminate post expenses if it ok.

fonske, 2024-10-25:
Ok thats fine.
I placed a copy here
https://github.com/fonske/clack-reader-v4/blob/ws1_no_tof/readme/Clack%20Tof%20Holder.stl

Closed 2024-11-30.

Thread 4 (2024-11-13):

Set Initial Value of Buttons

dfiore1230, 2024-11-13:
the initial value of the following buttons is unset ("unknown") which causes systems to report the entities as unknown.

1. Reset Fill Salt
2. Reset resinclean
3. Test Button regen stop
4. Test Button usepulse
5. Test Button motor run pulse
6. ESP Restart
7. ESP Restart (Safe mode)

Myself and many others have a sensor that lists out the unknown entities as a mechanism for troubleshooting.

As a suggestion these buttons should have an initial value, likely being the time of the initialization.

fonske, 2024-11-14:
isnt that normal when the button is never pushed?

Do you have a esphome code example of an initial value?

dfiore1230, 2024-11-14:
Well it can be, but presetting a value will enable existing monitoring to work unchanged.

I dont have experience with ESPHOME but i using HA you can set the initial value of a state pretty easily.

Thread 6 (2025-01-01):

Salt fill date

kkalitowski, 2025-01-01:
When clicking the 'Reset fill salt' button, the 'Salt fill on' date changes to something I can't make sense of.

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

- Date button was clicked: January 1, 2025 4:26pm
- Date 'Salt Fill on' was set to: December 31, 2024 18:40

That's something like 21h46m before my local time.

When flashing the board, I set the timezone to 'America/Chicago', which I got from following this chain of URLs:

1. https://esphome.io/components/time/sntp.html
2. https://esphome.io/components/time/#base-time-config
3. https://en.wikipedia.org/wiki/List_of_tz_database_time_zones

Am I doing something wrong here like choosing an incompatible timezone string, or is there something incorrect in the code? I did reflash the board to make certain I sent it the timezone I have in the YAML.

kkalitowski, 2025-01-02:
At @fonske 's suggestion, changing `clack.yaml` to use `platform: homeassistant` instead of `platform: sntp` resolved the issue.

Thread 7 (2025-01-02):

Pressing a Clack hard button causes detection of regeneration cycle

kkalitowski, 2025-01-02:
**Steps to reproduce**
1. Get the board in a steady, working state
2. Start some water flowing, note that the board reports the flow rate through Home Assistant
3. Press a button on the clack controller (e.g., Press Next to get the controller's flow rate to display)
I've been able to recreate this problem multiple times. Maybe the power draw of the LCD backlight might cause the board's power to drop and reboot?

**Problem**
At this point, strange stuff happens. The flow rate shown in HA stops updating (e.g., gets stuck at 1.4gpm). The 'Operation Time' shown in HA changes to -1h. The 'water meter' changes to 0 gallons.

**Partial resolution**
To get the flow meter working again, I have to press the 'Test button Regen stop' button in HA. This does not resolve everything though. For example, the 'Water meter' loses its count, the 'Water softener gallons left' resets to full capacity. The 'Operation time' remains at -1h.

fonske, 2025-01-02:
I have raised the minumum detection of power for regeneration cycle simulation from 1.0 watt to 1.2 watt.
The CE has a bit higher power consumption as it seems then the WS1, because of the LCD backlight probably.
Let me know if that works ok.

Changes are made
[link](https://github.com/fonske/clack-reader-v4/blob/ws1_usa/esphome/clack_ws1_usa/.clack-base.yaml#L1108-L1109)

kkalitowski, 2025-01-02:
Confirming that the update worked. I pressed a hard button and 'cycle step' remained at 'Idle'.

Closed 2025-01-02.

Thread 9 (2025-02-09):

Liters meter diff

OwlBawl, 2025-02-09:
For some time noticed that Reader's and my Clack WS1 water meters begin differ somewhy.
If i remember correctly on initial setup they were correct.

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

I've checked the initial capacity after regen, and it's correct on both - 2,76 m3

Clack's resin capacity is set to 0,72
and hardness to 260 ppm

fonske, 2025-02-09:
You can lower pulse per ltr a bit, so the liter counting goes a bit faster.

Closed 2025-03-13.

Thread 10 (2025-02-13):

I am interested in setting it up with my water softener.

hajar97, 2025-02-13:
I have attached some images of how my Clack WS1 CI UF control unit looks from outside and inside. Hopefully your system is compatible with it. Could you please confirm?

If so, I would be interested in purchasing your kit and setting it up with my HA. How can I best do that?

Thank you

hajar97, 2025-02-13:
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

fonske, 2025-02-13:
I think it might be possible.
What is the value of the power supply? 15 VDC or 12 VAC

You can contact me on my email adress on the front page

hajar97, 2025-02-13:
It says 15 VDC

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

fonske, 2025-02-13:
Then is should be possible.

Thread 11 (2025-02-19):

ESP home 2025.2.0 - breaking changes: Custom component -> External component

OwlBawl, 2025-02-19:
The "custom" component has been removed. Consider conversion to an external component.
[https://esphome.io/guides/contributing#a-note-about-custom-components](  https://esphome.io/guides/contributing#a-note-about-custom-components)

```
platform: custom
  lambda: |-
    auto wf = new WaterFlowSensor();
    App.register_component(wf);
    return {wf->clack_flow_rate};
  sensors:
    - name: Water flow rate
      icon: mdi:waves-arrow-right
      unit_of_measurement: L/min
      accuracy_decimals: 2
      id: clack_flow_rate
```

fonske, 2025-02-22:
Will take a while to have time and knowledge to make such a component.

If you are in need, you can install this addon
https://github.com/ginkage/MHI-AC-Ctrl-ESPHome/issues/123#issuecomment-2669511186

And use the 2024.12 version of esphome

Flappiee, 2025-02-27:
I used this and works fine: https://github.com/robertklep/esphome-custom-component

Just add this to your code:

`
external_components:
  - source:
      type: git
      url: https://github.com/robertklep/esphome-custom-component
    components: [ custom, custom_component ]
`

fonske, 2025-02-27:
@Flappiee
Nice workaround

Thanks

fonske, 2025-03-02:
For the WS1 branch there have been some revisions on the TOF2 sensor as an external component
The flowmeter now is based on pulsemeter instead of .h file
There were 2 extra choiches added for an Clack WS1 CI UF model  (upflow brining)
Instead of arduino, its now based on esp-idf
Big thanks to @hajar97

clack.yaml in your esphome directory needs to replaced too

I have tested the (new) code shortly and everything seems to be working.
Let me know if there are any issues.

OwlBawl, 2025-03-02:
Maybe it's possible to make TOF as external file also, so just comment on it would allow to use code without TOF connected?

fonske, 2025-03-02:
I tested without the TOF connected and the value stays 0 cm and no reboots on the esp anymore.

OwlBawl, 2025-03-02:
ws1 branch
https://github.com/fonske/clack-reader-v4/blob/ws1/esphome/clack.yaml

packages:
  remote_package:
    url: https://github.com/fonske/clack-reader-v4
    ref: ws1
    refresh: 0s
    files: [
      esphome/clack_ws1/.clack-base.yaml,
#      esphome/clack_ws1/.tof1.yaml,
      esphome/clack_ws1/.tof2.yaml,
      esphome/clack_ws1/.waterflow.yaml,
      esphome/clack_ws1/.clack-optional.yaml,
#      esphome/clack_ws1/.clack-labels-nl.yaml,
      esphome/clack_ws1/.clack-labels-en.yaml,
#      esphome/clack_ws1/.clack-labels-fr.yaml,
      esphome/clack_ws1/board-esp32-atom-s3.yaml,
    ]

While compiling....

```
src/esphome/components/pulse_meter/pulse_meter_sensor.cpp: In member function 'virtual void esphome::pulse_meter::PulseMeterSensor::loop()':
src/esphome/components/pulse_meter/pulse_meter_sensor.cpp:49:17: warning: '--' expression of 'volatile'-qualified type is deprecated [-Wvolatile]
   49 |     this->get_->count_--;
      |     ~~~~~~~~~~~~^~~~~~
src/esphome/components/pulse_meter/pulse_meter_sensor.cpp:57:17: warning: '++' expression of 'volatile'-qualified type is deprecated [-Wvolatile]
   57 |     this->get_->count_++;
      |     ~~~~~~~~~~~~^~~~~~
src/esphome/components/pulse_meter/pulse_meter_sensor.cpp: In static member function 'static void esphome::pulse_meter::PulseMeterSensor::edge_intr(esphome::pulse_meter::PulseMeterSensor*)':
src/esphome/components/pulse_meter/pulse_meter_sensor.cpp:132:9: warning: '++' expression of 'volatile'-qualified type is deprecated [-Wvolatile]
  132 |     set.count_++;
      |     ~~~~^~~~~~
src/esphome/components/pulse_meter/pulse_meter_sensor.cpp: In static member function 'static void esphome::pulse_meter::PulseMeterSensor::pulse_intr(esphome::pulse_meter::PulseMeterSensor*)':
src/esphome/components/pulse_meter/pulse_meter_sensor.cpp:152:9: warning: '++' expression of 'volatile'-qualified type is deprecated [-Wvolatile]
  152 |     set.count_++;
```

But seems working

william-sy, 2025-03-03:
Instelled it just now without problems, my TOF1 sensor is unresponsive so tomorrow ill migrate to TOF2. So far the rest all seems to be in order!

Thanks for the work!

martijndierckx, 2025-03-23:
So to be clear ... TOF1 will not be supported in 2025.2 and newer esphome versions?

fonske, 2025-03-23:
@martijndierckx
TOF1 is already a esphome external component, so no changes in that one needed.

Closed 2025-03-13.

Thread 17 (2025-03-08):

Support for WS1TC-S

mageali, 2025-03-08:
Less of an issue, more of a questions. Would this work qith the Clack WS1TC-S?

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

fonske, 2025-03-08:
Can you see what the power supply is giving?
Is it 12 VAC or 15 VDC.

It seems your softener is time based (not flow based), as i dont see a flowmeter connection.

It can work if power supply (15 VDC) is ok , but you will missing the flowmeter functions. (stays 0 in the software)

mageali, 2025-03-08:
Thank you for the quick reponse.

It's 15v.

I understand what you mean about the flow meter. I was hoping the data pins
on the left have some info. I'll investigate a bit and come back.

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

fonske, 2025-03-08:
Pins on the left side are probably to directly programming the chip on the clack pcb

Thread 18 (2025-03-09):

Spikes in waterflow registration

MWolthuis, 2025-03-09:
Hi Fonske,

First a thank you for this piece of hardware and software. Much appreciated.

Since the latest update the waterflow registration is way off. I get big spikes while it is counting the waterflow. In the previous version the calibration was correct. Tested it with filling a bottle and it was correct. Now it goes from the real value (let's say 5.3 l/m) to a spike with a reading of 35 l/m or even more.

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

Any idea what is going on?

fonske, 2025-03-09:
We changed it to be a pulsemeter to be more futureproof in updates with esphome.

Obviously not the best choice.
Will try to look into it and maybe reverse the updated/changed code
Thanks

hajar97, 2025-03-09:
Hey, I didn’t notice it before, but now checking my own readings I see I have the same spikes.

This is not affecting the total water metering, because it decreases the amount of water I use every day very accurately. This spikes are there only in the historical data. But do shout if its different for you.

Here is the documentation of pulse meter sensor for those who want to experiment with it:
https://esphome.io/components/sensor/pulse_meter.html

There are 2 main parameters that I think should hold the key to solve the spikes issue:
internal_filter and internal_filter_mode

I’ll try to play with them next week and see what values eliminate these strange spikes. If I find a solution I'll report back.

hajar97, 2025-03-09:
Yes, I am testing it too.

I also checked previous water_flow.h file and it had this line:
const int SENSOR_DEBOUNCE_MS = 10;

So I additionally added this line (because internal filter acts as debounce filter according to the documentation):
internal_filter: 10ms

Why don't you run it with your one setting change and I run it with my 2 settings change and we check in again in a couple of days to see how our historic data may have improved.

MWolthuis, 2025-03-09:
Will do. I just leave it with only the additional line: internal_filter_mode: PULSE

I'll let you know in a few days.

MWolthuis, 2025-03-12:
On my side it all seems good right now. No more spikes and when I used 1 litre of water the counter also added exactly 1 litre.

fonske, 2025-03-12:
@MWolthuis
Thank you for testing.
I added the line to the code on the main and ws1 branch.

hajar97, 2025-03-12:
Perfect, glad to hear. Then I will remove the extra line on my side as it is probably not needed.

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

Closed 2025-03-13.

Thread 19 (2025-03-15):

Water flow sensor on Clack Palace UF

maciejkosmida1, 2025-03-15:
Running this with Clark Palace UF
Connected to HA and running into some interesting readings

If I turn the water on just slightly the Water Flow reading is 0 while the total water consumption is still being added

fonske, 2025-03-15:
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

hajar97, 2025-03-15:
Confirm. I have the same behaviour that water flow shows 0 while total water usage is calculated correctly. This happens at flows lower than 1.5 litres or so. Will keep testing with various settings of the pulse meter and see if there is one that enables it to show smaller flows as well.

maciejkosmida1, 2025-03-15:
My minimum recorded value was 1.8x though to be fair the head itself minimum value shown on the display is 2l

hajar97, 2025-03-15:
Alright, I did some testing and came to the following discoveries:

1. Pulse Meter measures pulses per minute.
2. Timeout setting (which is currently set to 2s) decides how long to wait before deciding that no pulses equals flow has stopped. With 2s it means if there is no pulse in 2s flow is assumed to be 0.
3. So for a flow to register, there needs to be at least 1 pulse every 2 seconds, which equals to 30 pulses a minute.
4. If your Clack is set to 16.3 pulses per litre you will get 30 / 16.3 = 1.84 litres per minute. That's exactly what we are seeing - when flow is 1.84 litres per minute or higher it registers it well. When it is anything lower a timeout fires setting it to 0.
5. Previous version of water meter had a timeout of 6.5s. This means it would register water flow as low as 60/6.5/16.3 = 0.56.

There is a tradeoff to be had with timeout setting. If it is set low (e.g. 2s) then the advantage is that as soon as water flow drops it registers it immediately. But it doesn't register low volume flows. If we set timeout to higher values, then it can register lower volume flows, but it will react slower to when flow completely stops.

I guess the most optimal action here is to set timeout to 6.5s as it was previously.

hajar97, 2025-03-15:
Another option is to make timeout setting to be configurable on the dashboard, like pulses per litre is and then everyone could set it whatever preference they had. The setting would then need to be explained in the documentation though, so people would understand the tradeoff.

Closed 2025-05-29.

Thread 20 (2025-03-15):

Lost Voltage and Power readings

maciejkosmida1, 2025-03-15:
For some reason I lost Power and Voltage readings from all sources. Did I break something? I was tidying the cables in the enclosure

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

maciejkosmida1, 2025-03-15:
nothing useful in the logs...

maciejkosmida1, 2025-03-15:
I think I managed to break something

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

fonske, 2025-03-17:
Sended a new board.

Problem was the soldering islands not connected, so the I2C adress is random when ESP reboots.

I will close this issue now. Thanks

Closed 2025-03-17.

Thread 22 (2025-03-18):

[HomeAssistant] Integration reports warnings due to wrong data type

maciejkosmida1, 2025-03-18:
Rejestrator: homeassistant.components.sensor
Źródło: components/sensor/__init__.py:709
integracja: Sensor ([dokumentacja](https://www.home-assistant.io/integrations/sensor), [Problemy](https://github.com/home-assistant/core/issues?q=is%3Aissue+is%3Aopen+label%3A%22integration%3A+sensor%22))
Pierwsze zdarzenie: 12:52:23 (4 zdarzenia)
Ostatnio zalogowany: 12:52:23

Entity sensor.clack_water_softener_percent_ltr_left (<class 'homeassistant.components.esphome.sensor.EsphomeSensor'>) is using native unit of measurement '%' which is not a valid unit for the device class ('water') it is using; expected one of ['CCF', 'L', 'ft³', 'm³', 'gal']; Please update your configuration if your entity is manually configured, otherwise create a bug report at https://github.com/home-assistant/core/issues?q=is%3Aopen+is%3Aissue+label%3A%22integration%3A+esphome%22
Entity sensor.clack_water_softener_percent_time_left (<class 'homeassistant.components.esphome.sensor.EsphomeSensor'>) is using native unit of measurement '%' which is not a valid unit for the device class ('duration') it is using; expected one of ['ms', 'd', 'h', 'min', 's']; Please update your configuration if your entity is manually configured, otherwise create a bug report at https://github.com/home-assistant/core/issues?q=is%3Aopen+is%3Aissue+label%3A%22integration%3A+esphome%22
Entity sensor.clack_wifi_signal (<class 'homeassistant.components.esphome.sensor.EsphomeSensor'>) is using native unit of measurement '%' which is not a valid unit for the device class ('signal_strength') it is using; expected one of ['dB', 'dBm']; Please update your configuration if your entity is manually configured, otherwise create a bug report at https://github.com/home-assistant/core/issues?q=is%3Aopen+is%3Aissue+label%3A%22integration%3A+esphome%22
Entity sensor.clack_uptime (<class 'homeassistant.components.esphome.sensor.EsphomeSensor'>) is using native unit of measurement 'days' which is not a valid unit for the device class ('duration') it is using; expected one of ['ms', 'd', 'h', 'min', 's']; Please update your configuration if your entity is manually configured, otherwise create a bug report at https://github.com/home-assistant/core/issues?q=is%3Aopen+is%3Aissue+label%3A%22integration%3A+esphome%22

maciejkosmida1, 2025-03-18:
think this should be pretty easy to fix

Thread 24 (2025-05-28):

water consumption junkies by 1000l on fw update

ragg987, 2025-05-28:
This issue seems to have started about 2 or 3 months ago, after an esp32 fw update and a restart there reading increase by 1000l.

Screenshot below shows 2 fw updates on the same day, hence total increase is 2000l.

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

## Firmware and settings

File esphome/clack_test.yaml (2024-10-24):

substitutions:
  device_description: "Clack test for Atom s3 lite"
  timezone: "Europe/Amsterdam"

esphome:
  name: clack-test
  friendly_name: Clack Test
  name_add_mac_suffix: false


esp32:
  board: esp32-s3-devkitc-1
  framework:
    type: arduino

wifi:
  ssid: !secret wifi_ssid
  password: !secret wifi_password
  fast_connect: true

  # Enable fallback hotspot (captive portal) in case wifi connection fails
  ap:
    ssid: clack-test
    password: "configesp"
    ap_timeout: 15s

captive_portal:

# Sync time with sntp server
time:
  - platform: sntp
    id: sntp_time
    timezone: ${timezone}

# Enable logging
logger:
  baud_rate: 0
  logs:
    esp32.preferences: DEBUG
    sensor: DEBUG
    text_sensor: DEBUG
    switch: DEBUG
    button: DEBUG
    number: DEBUG
    component: ERROR


# Enable Home Assistant API
api:
  reboot_timeout: 0s

ota:
  - platform: esphome
  
web_server:
  port: 80


sensor:
# Diagnostics wifi and uptime      
  - platform: wifi_signal # Reports the WiFi signal strength/RSSI in dB
    id: clack_wifi_signal_db
    name: clack_wifi_signal_db
    update_interval: 60s
    entity_category: diagnostic
    internal: True

  - platform: uptime
    id: clack_uptime
    name: clack_uptime
    unit_of_measurement: days
    update_interval: 3600s
    accuracy_decimals: 1
    filters:
      - multiply: 0.000011574

# Text sensors with general information.
text_sensor:
  # Expose ESPHome version as sensor.
  - platform: version
    id: clack_version
    name: clack_version
    hide_timestamp: true
    icon: mdi:new-box
    entity_category: diagnostic

  # Expose WiFi information as sensor.
  - platform: wifi_info
    ip_address:
      name: Clack IP
      icon: mdi:ip-network
  
light:
#G35=RGB WS2812C-2020
  - platform: esp32_rmt_led_strip
    name: Led
    id: led
    rgb_order: GRB
    pin: 35
    num_leds: 4
#    brightness: 0.7
    # RMT 0 channels will be occupied by IR
    rmt_channel: 1
    chipset: ws2812
#    restore_mode: ALWAYS_ON
    internal: True

#G41=Button
binary_sensor:
  - platform: gpio
    id: esp_button
    pin:
      number: GPIO41
      inverted: true
      mode:
        input: true
        pullup: true
    internal: false
    filters:
      - delayed_off: 10ms


## ESP restart button
button:
  - platform: restart
    id: restart_button
    name: ESP restart

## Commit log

2024-08-06 Added test button motor
2024-08-06 modify test motor run button
2024-08-18 added 3d airgap
    [Airgap_v4.f3d, Airgap_v4.stl, Deksel airgap V2.stl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]
2024-08-20 added button motor run
2024-08-20 changed button motor run
2025-01-03 Update .clack-base.yaml
    changed minimum power for simulation
2025-02-25 Update .clack-base.yaml
    Increased capacity days to 28
2025-02-26 Update .clack-base.yaml
    Changed capacity litres step to be 10 litres to reflect the capacity precision that is shown on Clack WS1 display
2025-03-01 Update .clack-labels-en.yaml
    Added support for a text sensor that shows sequence of steps of selected regeneration mode
2025-03-01 Update .clack-base.yaml
    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
2025-03-01 Update board-esp32-atom-s3.yaml
    Added 400kHz frequency for i2c bus which is recommended for TOF component
2025-03-01 Update board-esp32-atom-s3.yaml
    Updated stop action with stop scripts for 2 upflow cycles
2025-03-02 Update .clack-base.yaml
    Fixed a bug that would briefly show wrong water meter value when changing capacity in litres setting.
2025-03-02 Update board-esp32-atom-s3.yaml
    Updated the board to use esp-idf framework, which is recommended for ESP32S3 boards
2025-03-02 added sensors
2025-03-16 Update .waterflow.yaml
    Increased default water flow timeout to 7s to match previous water flow setting.
2025-03-16 Update .clack-base.yaml
    Added configuration parameter for time delay for considering water flow stopped
2025-03-16 Update .clack-labels-en.yaml
    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
2025-03-16 Update clack_explanation_en.md
    Added description for Pulses per minute and Water flow timeout settings.
2025-03-16 Changed granularity of water flow timeout setting
2025-03-16 Update .clack-base.yaml
    Changed type of component for Water flow timeout
2025-03-16 Update .waterflow.yaml
    Lowered the frequency of updates during the water flow to 300ms to match the previous setting.
2025-03-30 Added flowmeter time delay
2026-01-30 Remove contact section from README
    Removed contact information for PCB purchases.
2026-02-24 Revise French translations and add new sensors
    Updated French translations for various terms and added new sensors for last regeneration, resinclean, and salt fill information.
2026-05-26 Replace clack_water_flow custom component with built-in pulse_meter platform
    The custom C++ component was polling GPIO in the main loop with a blocking
    debounce, which limited flow-rate timing resolution. Swap it for ESPHome's
    built-in pulse_meter platform, which uses a GPIO ISR with microsecond
    timestamps.
    - esphome/clack_ws1_usa/.clack-base.yaml: replace clack_water_flow sensor
    with pulse_meter (10ms PULSE-mode filter, 30s timeout). Convert pulses/min
    to gal/min via a lambda using the pulse_per_gallon global. Accumulate
    totalWaterUsage from the total: sub-sensor's on_value, gated by
    water_meter_freeze. Push clack_watermeter on each pulse and add a 300ms
    throttle filter to match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
2026-05-26 Gate clack_water_flowing on water_meter_freeze to suppress leak checks during regen
    With the pulse_meter migration, clack_flow_rate now publishes live values
    during regen instead of being held at its pre-freeze value. clack_water_flowing
    followed that, which produced rising edges that re-armed the check_leakage
    script during regen. AND the freeze flag into the lambda so the binary sensor
    reports false during regen, matching the prior behavior.
